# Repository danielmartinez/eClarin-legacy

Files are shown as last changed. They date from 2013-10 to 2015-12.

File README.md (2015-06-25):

eClarin
=======
eClarin is an Open Source project that brings you the opportunity to build an electronic aragonese bagpipe. It is based on the Arduino platform, 3D printing models and the USB MIDI Firmware.

How to build the hardware
-------------------------
The hardware can be built by following the steps in the "howto build the eChanter" http://www.echanter.com/home/howto-build. eClarin is also based on it, it is a cheap, easy and absolutly great way to make an electronic chanter... as they say: if you can solder, you can make it!

Maybe you will find helpfull the 3D models of chanters included here, you can print them with a 3D printer, and use them for the case.

How to load the firmware
------------------------
This project runs on an Arduino board, so you can get the sketch from this source code and load to it.

Once you load the sketch on the board you can program the Moco LUFA Firmware, that allows the PC to recognize the Arduino board as a standard USB MIDI controller. You can find that firmware and instructions here http://morecatlab.akiba.coocan.jp/lab/index.php/aruino/midi-firmware-for-arduino-uno-moco/?lang=en

I included that repository at this one as submodule, maybe you want to clone the whole project with --recursive option (or doing git submodule update if you already cloned whitout that option).

I want to play it!
------------------
Sure! When you have built it and have programmed the arduino board, plug it in your computer, it must be recognized as an USB MIDI controller that allows you to talk MIDI commands with your prefered MIDI synth software (Mine is fluidsynth).

Why eClarin?
------------
Yeah, that's a good question. All of this stuff is eChanter based and I can only thank the author for that. In a little tribute to him and using the word that names this part of the bagpipe (clarin means chanter), I chose eClarin for the project's name.

Can I help?
-----------
Maybe. If you think you can help, then you can help! Contact me about your suggestions, codes, ideas of whatever else you want, I'm pretty sure we can make it better together.

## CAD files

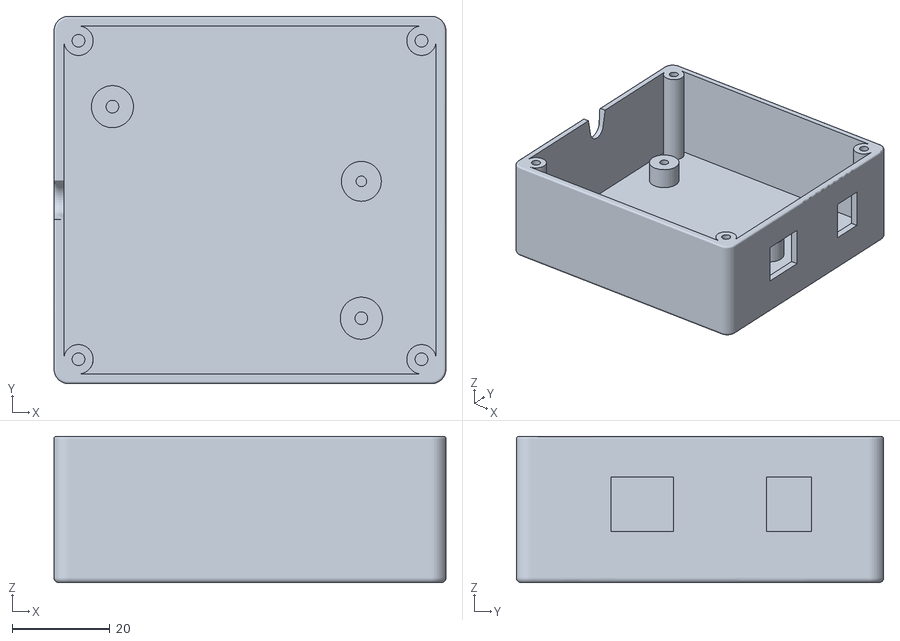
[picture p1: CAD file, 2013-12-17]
models/stl/cajita_base.stl
80.0 x 75.0 x 29.9

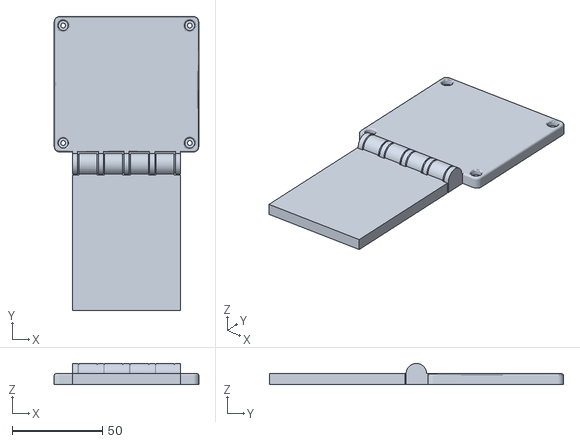
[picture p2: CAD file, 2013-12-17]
models/stl/cajita_tapa.stl
80.0 x 162.7 x 11.7

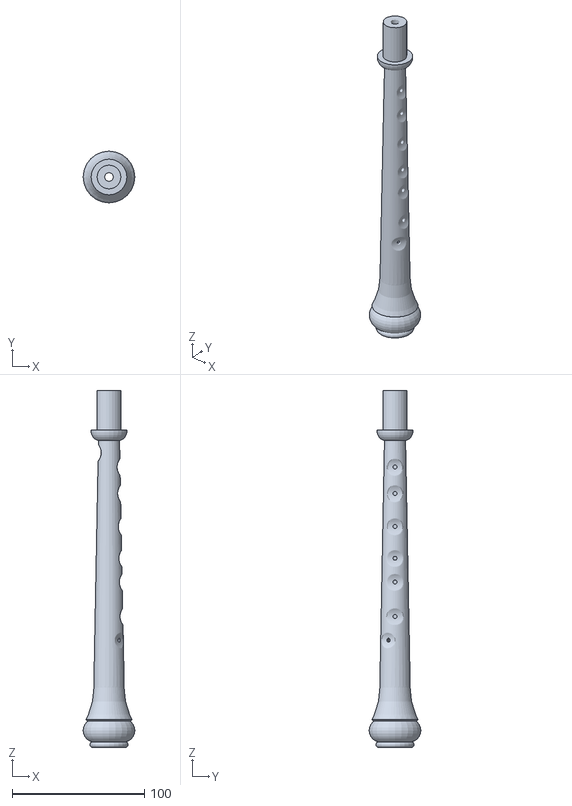
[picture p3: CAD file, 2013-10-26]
models/stl/clarin.stl
39.1 x 39.1 x 270.0

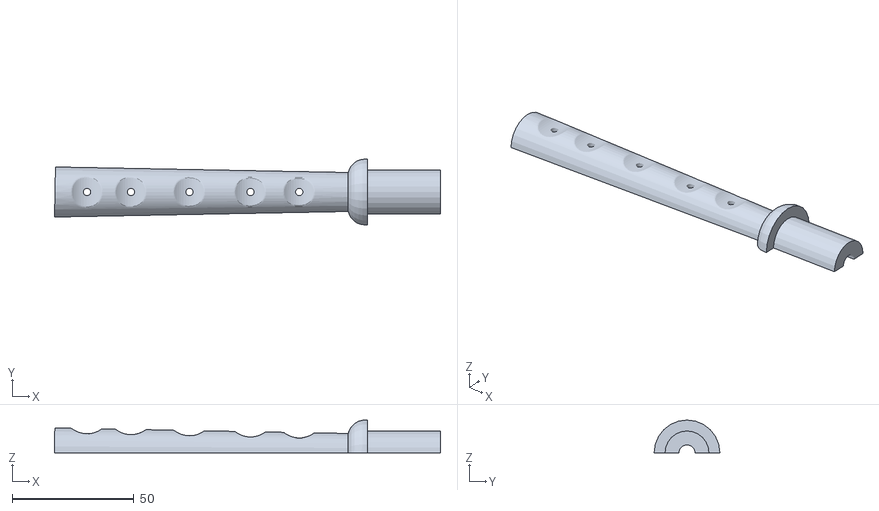
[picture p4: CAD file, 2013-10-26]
models/stl/clarincortado1.stl
158.2 x 27.0 x 13.5

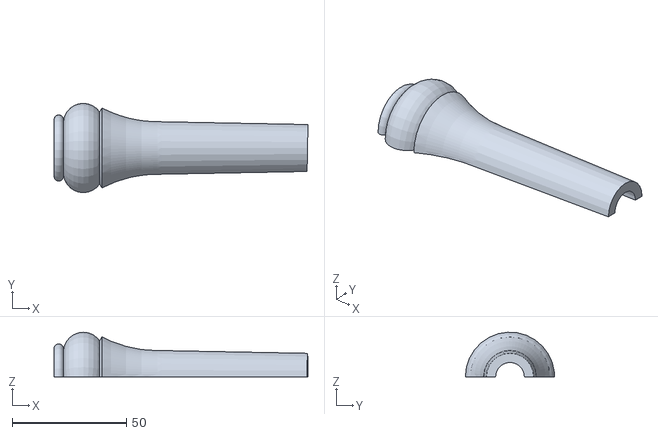
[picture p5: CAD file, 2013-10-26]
models/stl/clarincortado2.stl
111.2 x 39.1 x 19.5

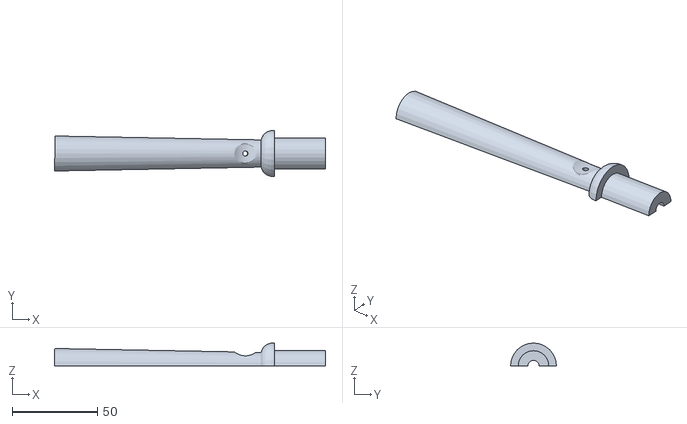
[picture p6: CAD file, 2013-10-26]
models/stl/clarincortado0.stl
159.1 x 27.0 x 13.5

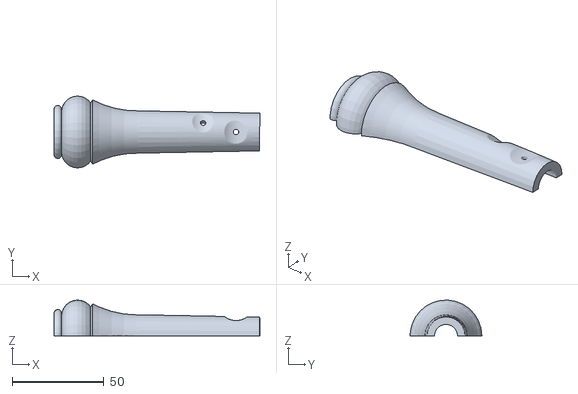
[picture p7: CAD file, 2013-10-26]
models/stl/clarincortado3.stl
112.2 x 39.1 x 19.5

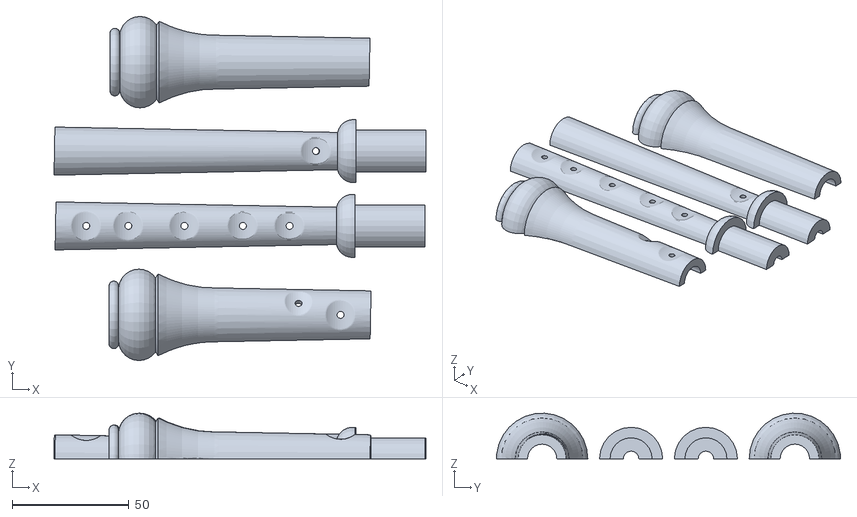
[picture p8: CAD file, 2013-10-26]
models/stl/clarinconjunto.stl
159.1 x 147.2 x 19.5

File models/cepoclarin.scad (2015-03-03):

radio=14;
altura=60;
grosor=2.5;
ancho=50;
largo=75;
diametroclarin=18;
alturaclarin=30;
$fn=200;
difference(){
  union(){
    //Cepo body
    difference() {
    translate([-(largo-2*radio)/2,-(ancho-2*radio)/2,0])
      minkowski() {
        cylinder(altura/2,r=radio);
        cube([largo-2*radio,ancho-2*radio,altura/2]);
      }
    translate([0,0,grosor/2])
      resize([(largo-grosor),(ancho-grosor),altura+grosor])
        translate([-(largo-2*radio)/2,-(ancho-2*radio)/2,0])
          minkowski() {
            cylinder(altura/2,r=radio);
            cube([largo-2*radio,ancho-2*radio,altura/2]);
          }
    }
    //Chanter support
    cylinder(d=diametroclarin+grosor+0.75,h=alturaclarin);
    //Slice switch support
    translate([grosor-0.7+(largo-radio)/2,-2.5,0]) cube([4,5,7+6+altura/2]);
    //VS1053 Module support
    translate([-2-45/2,-5.3-grosor+ancho/2,0]) cube([3,7,altura-5]);
    mirror([1,0,0]) translate([-2-45/2,-5.3-grosor+ancho/2,0]) cube([3,7,altura-5]);
    //ARDUINO NANO/MINI PRO support
    translate([7-largo/2,-8/2,0]) cube([6,8,15]);
  }
  //LED Hole
  translate([-2-largo/2,0,33]) rotate([0,90,0]) cylinder(d=3,h=2*grosor);
  //Slide switch Hole
  translate([(largo-radio)/2,-2,altura/2]) cube([grosor+5,4,7]);
  //Chanter Hole
  translate([0,0,-1]) cylinder(d=diametroclarin+0.75,h=alturaclarin+2);
  //VS1053
  translate([-45/2,-grosor-4+ancho/2,15]) cube([45,2,45]);
  //ARDUINO
  translate([9-largo/2,-20/2,10]) cube([1,20,15]);
}

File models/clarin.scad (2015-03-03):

$fn=200;
difference(){
rotate_extrude(){
difference() {
    union() {
      polygon([[0,0],[26/2,0],[26/2,16],[35/2,21],[23/2,21+26],[21/2,21+26+35],[20/2,21+26+35+30],[19/2,21+26+35+30+30],[18/2,21+26+35+30+30+30],[17/2,21+26+35+30+30+30+30],[16/2,21+26+35+30+30+30+30+30],[27/2,21+26+35+30+30+30+30+30+8],[18/2,21+26+35+30+30+30+30+30+8],[18/2,21+26+35+30+30+30+30+30+8+30],[0,21+26+35+30+30+30+30+30+8+30]]);
      translate([10,12,0]) circle(9);
      translate([13,2,0]) circle(2);
      intersection() {
        translate([4,1+21+26+35+30+30+30+30+30+8]) circle(10);
        translate([0,1+26+35+30+30+30+30+30+8])square([20,20]);
      }
    }
    translate([60+23/2,21+26] )circle(60);
  }
}

translate([-15,16,222]) rotate([0,90,0]) cylinder(h=30,r=10);
translate([-15,-16.1,212]) rotate([0,90,0]) cylinder(h=30,r=10);
translate([-15,-16.4,192]) rotate([0,90,0]) cylinder(h=30,r=10);
translate([-15,-16.9,167]) rotate([0,90,0]) cylinder(h=30,r=10);
translate([-15,-17.4,143]) rotate([0,90,0]) cylinder(h=30,r=10);
translate([-15,-17.8,125]) rotate([0,90,0]) cylinder(h=30,r=10);
translate([-15,-18.3,99]) rotate([0,90,0]) cylinder(h=30,r=10);
rotate([0,0,-30]) translate([-15,-18.9,81]) rotate([0,90,0]) cylinder(h=30,r=10);
}
//rotate([0,0,-90]) color("grey") translate([-98.5,-94.5,0]) import("clarin2.stl");

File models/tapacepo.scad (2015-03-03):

radio=14;
altura=1;
grosor=2.5;
ancho=50;
largo=75;
diametroclarin=18;
alturaclarin=30;
$fn=200;
difference () {
union() {
translate([-(largo-2*radio)/2,-(ancho-2*radio)/2,0])
      minkowski() {
        cylinder(altura/2,r=radio);
        cube([largo-2*radio,ancho-2*radio,altura/2]);
      }

translate([0,0,-1+grosor/2])
      resize([(largo-grosor),(ancho-grosor),altura+grosor+2])
        translate([-(largo-2*radio)/2,-(ancho-2*radio)/2,0])
          minkowski() {
            cylinder(altura/2,r=radio);
            cube([largo-2*radio,ancho-2*radio,altura/2]);
          }
}
translate([0,0,0.5+grosor/2])
      resize([(largo-grosor-grosor),(ancho-grosor-grosor),altura+grosor+5])
        translate([-(largo-2*radio)/2,-(ancho-2*radio)/2,0])
          minkowski() {
            cylinder(altura/2,r=radio);
            cube([largo-2*radio,ancho-2*radio,altura/2]);
          }
translate([12.5-45/2,-3-grosor-4+ancho/2,-1]) cylinder(d=5,h=10);
translate([largo/2-grosor-10,-4.5,-1]) cube([5,9,10]);
}

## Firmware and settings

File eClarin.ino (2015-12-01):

/*
 Copyright (C) 2015 Daniel Martinez <entaltoaragon@gmail.com>

 This program is free software; you can redistribute it and/or
 modify it under the terms of the GNU General Public License
 version 2 as published by the Free Software Foundation.
*/
/**************************************************************/
// CONFIGURATION
#define SENSOR_PINS             {2,3,4,5,6,7,8,9}
//#define BOTO_SENSOR           A4

#define VS1053_MIDI_SYNTH
#ifdef VS1053_MIDI_SYNTH
  #define XCS_PIN               A3
  #define XDCS_PIN              A2
  #define DREQ_PIN              A1
  #define XRST_PIN              A0
#else
  #define LED                   13 //can't use pin 13 for led if SPI communication is in use
#endif

#define SERIAL_MIDI              1

#define TRIGGER_VAL              8 // sensor trigger value (<val is on, >= val is off)
#ifdef BOTO_SENSOR
  #define BORDON_TRIGGER_VAL    20
  #define BORDONETA_TRIGGER_VAL 35
  #define CLARIN_TRIGGER_VAL    55
#endif

//#define SERIAL_DEBUG
#ifdef SERIAL_DEBUG
  //#define VERBOSE_DEBUG0   //Digitation events
  //#define VERBOSE_DEBUG1   //Start/stop events
#endif

//#define STORE_CONFIG_ON_EEPROM
#ifdef STORE_CONFIG_ON_EEPROM
  #define EEPROM_ADDR_INSTRUMENT 0
  #define EEPROM_ADDR_BORDON 1
  #define EEPROM_ADDR_BORDONETA 2
  #define EEPROM_ADDR_VOLUME 3
  #define CONFIG_RESET_START_POSITION B00000000
#endif

/**************************************************************/
// AUTOMATIC DEFINES
#include <Arduino.h>
#ifdef VS1053_MIDI_SYNTH
  #include <SPI.h>
  #include "V1053MidiSynth.h"
  V1053MidiSynth synth(XRST_PIN,DREQ_PIN,XDCS_PIN,XCS_PIN);
#endif
#ifdef SERIAL_MIDI
  #undef SERIAL_DEBUG
  #include <SoftwareSerial.h>
  SoftwareSerial midiSerial(0, SERIAL_MIDI);
#endif
#ifdef STORE_CONFIG_ON_EEPROM
  #include <EEPROM.h>
#endif
#ifdef SERIAL_DEBUG
  #include "GM1.h"
#endif

/**************************************************************/
//INITIALIZATION AND GLOBAL VARS
uint8_t pins[]=SENSOR_PINS;
byte currentpos=0, previouspos;
uint8_t previous=0x48;
uint8_t instrument=109, vol=127;
int fsrValue;
boolean bordon=true, bordoneta=true;
boolean bordonPlaying=false, bordonetaPlaying=false;
boolean playing=false;


/**************************************************************/
int msgMidi(int cmd, int note, int vel) {
#ifdef SERIAL_MIDI
  midiSerial.write(cmd);
  midiSerial.write(note);
  midiSerial.write(vel);
#endif
#ifdef VS1053_MIDI_SYNTH
  synth.midiWriteData(cmd,note,vel);
#endif
}

void setInstrument(uint8_t channel, uint8_t instrument) {
  msgMidi((0xC0 | channel),instrument,instrument);
}

void noteOn(uint8_t channel, uint8_t note) {
  msgMidi((0x90 | channel),note,120);
}

void noteOff(uint8_t channel, uint8_t note) {
  msgMidi((0x80 | channel),note,120);
}

void playNote(uint8_t want, uint8_t have) {
  if ((have!=want) && playing) {
    noteOff(0,have);
    noteOn(0,want);
    previous=want;
  }
}

uint8_t readCapacitivePin(int pinToMeasure) {
  // Variables used to translate from Arduino to AVR pin naming
  volatile uint8_t* port;
  volatile uint8_t* ddr;
  volatile uint8_t* pin;
  // Here we translate the input pin number from
  //  Arduino pin number to the AVR PORT, PIN, DDR,
  //  and which bit of those registers we care about.
  byte bitmask;
  port = portOutputRegister(digitalPinToPort(pinToMeasure));
  ddr = portModeRegister(digitalPinToPort(pinToMeasure));
  bitmask = digitalPinToBitMask(pinToMeasure);
  pin = portInputRegister(digitalPinToPort(pinToMeasure));
  // Discharge the pin first by setting it low and output
  *port &= ~(bitmask);
  *ddr  |= bitmask;
  delay(1);
  uint8_t SREG_old = SREG; //back up the AVR Status Register
  // Prevent the timer IRQ from disturbing our measurement
  noInterrupts();
  // Make the pin an input with the internal pull-up on
  *ddr &= ~(bitmask);
  *port |= bitmask;

  // Now see how long the pin to get pulled up. This manual unrolling of the loop
  // decreases the number of hardware cycles between each read of the pin,
  // thus increasing sensitivity.
  uint8_t cycles = 17;
       if (*pin & bitmask) { cycles =  0;}
  else if (*pin & bitmask) { cycles =  1;}
  else if (*pin & bitmask) { cycles =  2;}
  else if (*pin & bitmask) { cycles =  3;}
  else if (*pin & bitmask) { cycles =  4;}
  else if (*pin & bitmask) { cycles =  5;}
  else if (*pin & bitmask) { cycles =  6;}
  else if (*pin & bitmask) { cycles =  7;}
  else if (*pin & bitmask) { cycles =  8;}
  else if (*pin & bitmask) { cycles =  9;}
  else if (*pin & bitmask) { cycles = 10;}
  else if (*pin & bitmask) { cycles = 11;}
  else if (*pin & bitmask) { cycles = 12;}
  else if (*pin & bitmask) { cycles = 13;}
  else if (*pin & bitmask) { cycles = 14;}
  else if (*pin & bitmask) { cycles = 15;}
  else if (*pin & bitmask) { cycles = 16;}

  // End of timing-critical section; turn interrupts back on if they were on before, or leave them off if they were off before
  SREG = SREG_old;

  // Discharge the pin again by setting it low and output
  //  It's important to leave the pins low if you want to 
  //  be able to touch more than 1 sensor at a time - if
  //  the sensor is left pulled high, when you touch
  //  two sensors, your body will transfer the charge between
  //  sensors.
  *port &= ~(bitmask);
  *ddr  |= bitmask;

  return cycles;
}

uint8_t readPins(){
  uint8_t positions=0, val;
  for (uint8_t i = 0; i < 8; i++) {
    val=readCapacitivePin(pins[i]);
    if (val <= TRIGGER_VAL) bitClear(positions,i);
    else bitSet(positions,i);
    #ifdef VERBOSE_DEBUG0
      Serial.print(val);
      Serial.print(' ');
    #endif
  }
  #ifdef VERBOSE_DEBUG0
    Serial.print(positions,BIN);
    Serial.println(" ");
  #endif
  return positions;
}

void readConfig(){
  #ifdef STORE_CONFIG_ON_EEPROM
    instrument=EEPROM.read(EEPROM_ADDR_INSTRUMENT);
    bordon=EEPROM.read(EEPROM_ADDR_BORDON);
    bordoneta=EEPROM.read(EEPROM_ADDR_BORDONETA);
    vol=EEPROM.read(EEPROM_ADDR_VOLUME);
  #endif
  #ifdef SERIAL_DEBUG
    Serial.println("Settings loaded from EEPROM");
  #endif
}

void writeConfig(){
  #ifdef STORE_CONFIG_ON_EEPROM
    EEPROM.write(EEPROM_ADDR_INSTRUMENT,instrument);
    EEPROM.write(EEPROM_ADDR_BORDON,bordon);
    EEPROM.write(EEPROM_ADDR_BORDONETA,bordoneta);
    EEPROM.write(EEPROM_ADDR_VOLUME,vol);
    #ifdef SERIAL_DEBUG
      Serial.print("Settings saved to EEPROM - Instrument: ");
      Serial.print(instrument);
      Serial.print(", bordon ");
      if (bordon) Serial.print("ON");
      else Serial.print("OFF");
      Serial.print(", bordoneta ");
      if (bordoneta) Serial.print("ON");
      else Serial.print("OFF");
      Serial.print(", volume: ");
      Serial.print(vol);
      Serial.println("");
    #endif
  #endif
}

void startClarin() {
  noteOff(0,previous);
  setInstrument(0,instrument);
  playing=true;
  playNote(previous,0);
  #ifndef VS1053_MIDI_SYNTH
    digitalWrite(LED,HIGH);
  #endif
  #ifdef VERBOSE_DEBUG1
    Serial.println("Clarin start");
  #endif
}

void stopClarin() {
  noteOff(0,previous);
  playing=false;
  #ifndef VS1053_MIDI_SYNTH
    digitalWrite(LED,LOW);
  #endif
  #ifdef VERBOSE_DEBUG1
    Serial.println("Clarin stop");
  #endif
}

void startBordon() {
  noteOff(1,0x30);
  setInstrument(1,instrument);
  if (bordon) noteOn(1,0x30);
  bordonPlaying=true;
  #ifdef VERBOSE_DEBUG1
    Serial.println("Bordon start");
  #endif
}

void stopBordon() {
  noteOff(1,0x30);
  bordonPlaying=false;
  #ifdef VERBOSE_DEBUG1
    Serial.println("Bordon stop");
  #endif
}

void startBordoneta() {
  noteOff(2,0x3C);
  setInstrument(2,instrument);
  if (bordoneta) noteOn(2,0x3C);
  bordonetaPlaying=true;
  #ifdef VERBOSE_DEBUG1
    Serial.println("Bordoneta start");
  #endif
}

void stopBordoneta() {
  noteOff(2,0x3C);
  bordonetaPlaying=false;
  #ifdef VERBOSE_DEBUG1
    Serial.println("Bordoneta stop");
  #endif
}

void startPlayback() {
  startBordon();
  startBordoneta();
  startClarin();
  #ifdef VERBOSE_DEBUG1
    Serial.println("Playback start");
  #endif
}

void stopPlayback() {
  stopClarin();
  stopBordoneta();
  stopBordon();
  #ifdef VERBOSE_DEBUG1
    Serial.println("Playback stop");
  #endif
}

void setInstrument() {
  stopPlayback();
  setInstrument(0,instrument);
  setInstrument(1,instrument);
  setInstrument(2,instrument);
  #ifdef SERIAL_DEBUG
    char buffer[30];
    Serial.print("Instrument set to ");
    strcpy_P(buffer,(char*)pgm_read_word(&(instrumentNames[instrument])));
    Serial.println(buffer);
  #endif
  startPlayback();
}

void setup() {
  #ifdef VS1053_MIDI_SYNTH
    synth.begin();
  #else
    pinMode(LED,OUTPUT);
  #endif
  #ifdef SERIAL_MIDI
    midiSerial.begin(31250);
  #elif defined(SERIAL_DEBUG)
    Serial.begin(115200);
  #endif
  #ifdef fsrAnalogPin
    pinMode(fsrAnalogPin, INPUT);
  #endif
  delay(5);
  #ifdef STORE_CONFIG_ON_EEPROM
    if (readPins()==CONFIG_RESET_START_POSITION) {
      writeConfig();
      #ifdef SERIAL_DEBUG
        Serial.print("DEFAULT ");
      #endif
    }
    else {
      readConfig();
      #ifdef SERIAL_DEBUG
        Serial.print("Saved ");
      #endif
    }
  #endif
  #ifdef SERIAL_DEBUG
    Serial.print("Settings loaded - Instrument: ");
    Serial.print(instrument);
    Serial.print(", bordon ");
    if (bordon) Serial.print("ON");
    else Serial.print("OFF");
    Serial.print(", bordoneta ");
    if (bordoneta) Serial.print("ON");
    else Serial.print("OFF");
    Serial.print(", volume: ");
    Serial.print(vol);
    Serial.println("");
  #endif
  setInstrument();
}

void loop() {
    #ifdef BOTO_SENSOR
      fsrValue=analogRead(BOTO_SENSOR);
      if (fsrValue<BORDON_TRIGGER_VAL) {
        if (bordonPlaying) stopBordon();
      }
      else if (!bordonPlaying) startBordon();
      if (fsrValue<BORDONETA_TRIGGER_VAL) {
        if (bordonetaPlaying) stopBordoneta();
      }
      else if (!bordonetaPlaying) startBordoneta();
      if (fsrValue<CLARIN_TRIGGER_VAL)  {
        if (playing) stopClarin();
      }
      else if (!playing) startClarin();
    #endif
    currentpos=readPins();
    if (currentpos!=previouspos)
    switch (currentpos) {
     case B01111101: ;; //DoA
     case B00000000: playNote(0x54,previous); break; //DoA
     case B00000001: ;; //Si
     case B01110001: playNote(0x53,previous); break; //Si
     case B00000101: ;; //Sib
     case B00000010: ;; //Sib
     case B01110101: playNote(0x52,previous); break; //Sib
     case B00000011: ;; //La
     case B01110011: playNote(0x51,previous); break; //La
     case B00001011: ;; //Lab
     case B00101011: ;; //Lab
     case B01101011: ;; //Lab
     case B01110110: playNote(0x50,previous); break; //Lab
     case B00000111: ;; //Sol
     case B01110111: playNote(0x4F,previous); break; //Sol
     case B00110111: playNote(0x4E,previous); break; //Fa#
     case B00001111: ;; //Fa
     case B11101111: ;; //Fa
     case B01101111: playNote(0x4D,previous); break; //Fa
     case B00011111: playNote(0x4C,previous); break; //Mi
     case B01011111: playNote(0x4B,previous); break; //Mib
     case B00111111: playNote(0x4A,previous); break; //Re
     case B10111111: playNote(0x49,previous); break; //Do#
     case B01111111: playNote(0x48,previous); break; //Do
     case B11111111: playNote(0x47,previous); break; //SiB
     
     case B10000010: ++instrument%=128; setInstrument(); writeConfig(); break;
     case B10000100: --instrument%=128; setInstrument(); writeConfig(); break;
     case B10001000: if (bordon=!bordon) startBordon();
                     else stopBordon();
                     #ifdef SERIAL_DEBUG
                       Serial.print("Set bordon ");
                       if (bordon) Serial.println("ON");
                       else Serial.println("OFF");
                     #endif
                     writeConfig(); break;
     case B10010000: if (bordoneta=!bordoneta) startBordoneta();
                     else stopBordoneta();
                     #ifdef SERIAL_DEBUG
                       Serial.print("Set bordoneta ");
                       if (bordoneta) Serial.println("ON");
                       else Serial.println("OFF");
                     #endif
                     writeConfig(); break;
     case B10100000: if (playing=!playing) startClarin();
                     else stopClarin(); break;
     /*case B10000011: msgMidi(0xB0,0x07,vol+=5); break;
     case B10000101: msgMidi(0xB0,0x07,vol-=5); break;*/
    }
    previouspos=currentpos;
}

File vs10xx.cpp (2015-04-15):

/*
 * vs10xx.cpp
 * A library for MusicShield 2.0
 *
 * Copyright (c) 2012 seeed technology inc.
 * Website    : www.seeed.cc
 * Author     : Jack Shao (jacky.shaoxg@gmail.com)
 * Create Time: Mar 2014
 * Change Log :
 *
 * The MIT License (MIT)
 *
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
 * THE SOFTWARE IS PROVIDED "AS IS", WITHOUT WARRANTY OF ANY KIND, EXPRESS OR
 * IMPLIED, INCLUDING BUT NOT LIMITED TO THE WARRANTIES OF MERCHANTABILITY,
 * FITNESS FOR A PARTICULAR PURPOSE AND NONINFRINGEMENT. IN NO EVENT SHALL THE
 * AUTHORS OR COPYRIGHT HOLDERS BE LIABLE FOR ANY CLAIM, DAMAGES OR OTHER
 * LIABILITY, WHETHER IN AN ACTION OF CONTRACT, TORT OR OTHERWISE, ARISING FROM,
 * OUT OF OR IN CONNECTION WITH THE SOFTWARE OR THE USE OR OTHER DEALINGS IN
 * THE SOFTWARE.
 */


#include <SPI.h>
#include "vs10xx.h"

//software patch for MIDI Play
const unsigned short gVS1053_MIDI_Patch[28]={
/*if you don't let GPIO1 = H,please send this patch by spi*/
0x0007, 0x0001, 0x8050, 0x0006, 0x0014, 0x0030, 0x0715, 0xb080, /* 0 */
0x3400, 0x0007, 0x9255, 0x3d00, 0x0024, 0x0030, 0x0295, 0x6890, /* 8 */
0x3400, 0x0030, 0x0495, 0x3d00, 0x0024, 0x2908, 0x4d40, 0x0030, /* 10 */
0x0200, 0x000a, 0x0001, 0x0050,
};

VS10XX::VS10XX(uint8_t _VS_XRESET, uint8_t _VS_DREQ, uint8_t _VS_XDCS, uint8_t _VS_XCS):
  VS_XRESET(_VS_XRESET), VS_DREQ(_VS_DREQ), VS_XDCS(_VS_XDCS), VS_XCS(_VS_XCS)
{
}

/*
 **@ function name: init
 **@ usage:init the vs10xx chip
 **@ input:none
 **@ retval:none
*/
void VS10XX::init(void)
{
  SPI.begin();
  SPI.setClockDivider(SPI_CLOCK_DIV16);
  initIO();
  reset();
}

/*
 **@ function name: initForMidiFmt
 **@ usage:init the vs10xx chip for midi Mode
 **@ input:none
 **@ retval:none
*/
void VS10XX::initForMidiFmt(void)
{
  //init IO
  initIO();

  //init SPI
  SPI.begin();
  SPI.setBitOrder(MSBFIRST);
  SPI.setDataMode(SPI_MODE0);
  SPI.setClockDivider(SPI_CLOCK_DIV16);
  //SPI.transfer(0xFF);	//transfer a dump

  //reset the chip
  reset();
  //load MIDI plugin
  loadMidiPlugin();
}

void VS10XX::initIO(void)
{
  pinMode(VS_XRESET, OUTPUT);
  pinMode(VS_DREQ, INPUT);
  pinMode(VS_XDCS, OUTPUT);
  pinMode(VS_XCS, OUTPUT);
  digitalWrite(VS_XDCS, HIGH);
  digitalWrite(VS_XCS, HIGH);
}

void VS10XX::writeRegister(unsigned char addressbyte, unsigned char highbyte, unsigned char lowbyte)
{
  // while (!readDREQ());
  deselectDataBus();
  selectControlBus();
  SPI.transfer(VS_WRITE_COMMAND);
  SPI.transfer((addressbyte));
  SPI.transfer((highbyte));
  SPI.transfer((lowbyte));
  deselectControlBus();
}

void VS10XX::writeRegister(unsigned char addressbyte, unsigned int value)
{
  writeRegister(addressbyte, value >>8, value & 0xff);
}

void VS10XX::writeData(unsigned char *databuf, unsigned char datalen)
{
  selectDataBus();
  while (!readDREQ());
  while (datalen--)
  {
    SPI.transfer(*databuf++);
  }
  deselectDataBus();
}

unsigned int VS10XX::readRegister(unsigned char addressbyte)
{
  unsigned int result = 0;
  unsigned char highbyte = 0;
  unsigned char lowbyte = 0;
  deselectDataBus();
  selectControlBus(); //XCS = 0
  SPI.transfer(VS_READ_COMMAND); //send read command
  SPI.transfer(addressbyte);    //send register address
                                //be careful: when read 0xff,dump it,and read agin
                                //while((h = SPIGetChar())== 0xff);
  highbyte = SPI.transfer(0xff);
  //while((l = VsReadByte())== 0xff);
  lowbyte = SPI.transfer(0xff);

  result = (((unsigned int)highbyte << 8) | lowbyte);
  deselectControlBus();
  return result;
}
// reset for vs10xx
void VS10XX::reset(void)
{
  putInReset();
  delay(100); //it is a must
  /* Send dummy SPI byte to initialize atmel SPI */
  ////SPIPutCharWithoutWaiting(0xFF);
  deselectControlBus();
  deselectDataBus();
  releaseFromReset();
  while (!readDREQ());
  /* Set clock register, doubler etc. */
  writeRegister(SPI_CLOCKF, 0xc0, 0x00);
  Serial.print("\r\nVS10xx Clock Frq: 0x");
  Serial.println(readRegister(SPI_CLOCKF), HEX);
  /* Wait for DREQ */
  while (!readDREQ());
  softReset(); //comment this, as it will be executed everytime playing a music file.

  writeRegister(SPI_WRAMADDR, 0xc0, 0x13);

  /* Switch on the analog parts */
  setVolume(40, 40);
  //setVolume(0xff,0xff);
  //SPISetFastClock();
}
/** Soft Reset of VS10xx (Between songs) */
void VS10XX::softReset(void)
{
  /* Soft Reset of VS10xx */
  writeRegister(SPI_MODE, 0x08, 0x04); /* Newmode, Reset, No L1-2 */
  //Delay(1);
  while (!readDREQ()); /* wait for startup */
  //setup I2S (see page77 of the datasheet of vs1053 )
  //set GPIO0 as output
  writeRegister(SPI_WRAMADDR, 0xc0, 0x17);
  writeRegister(SPI_WRAM, 0x00, 0xf0);
  //enable I2S (MCLK enabled, 48kHz sample rate)
  writeRegister(SPI_WRAMADDR, 0xc0, 0x40);
  writeRegister(SPI_WRAM, 0x00, 0x0C);
  while (!readDREQ());
  //LoadUserPatch();
}
/** Set VS10xx Volume Register */
void VS10XX::setVolume(unsigned char leftchannel, unsigned char rightchannel)
{
  writeRegister(11, (leftchannel), (rightchannel));
}

void VS10XX::sendZerosToVS10xx(void)
{
  unsigned int i;
  selectDataBus();
  for (i = 0; i < 2048; i++)
  {
    while (!readDREQ());
    SPI.transfer(0);
  }
  deselectDataBus();
}

/*
 **@ function name: loadMidiPatch
 **@ usage:load a software patch for vs10xx
 **@ input:none
 **@ retval:none
*/
void VS10XX::loadMidiPlugin(void)
{
  int i=0;
  Serial.print("load MIDI Plugin...\r\n");
  while(i < sizeof(gVS1053_MIDI_Patch)/sizeof(gVS1053_MIDI_Patch[0]))
  {
    unsigned short addr, n, val;
    addr = gVS1053_MIDI_Patch[i++];
    n = gVS1053_MIDI_Patch[i++];
    while(n--)
    {
      val = gVS1053_MIDI_Patch[i++];
      writeRegister(addr, val >> 8, val&0xff);
    }
  }
  Serial.print("done\r\n");
}
/****************The end***********************************************/

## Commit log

2013-10-26 Added main arduino sketch file
2013-10-26 Added a chanter model stl files
    [clarin2.stl, clarinconjunto.stl, clarincortado0.stl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]
2013-12-17 Arduino case model with FRS lid mount
    [cajita_base.stl, cajita_tapa.stl]
2015-02-16 Updated readCapacitivePin code from http://playground.arduino.cc/Code/CapacitiveSensor
2015-03-03 OpenSCAD files for portable model
    [cepoclarin.scad, clarin.scad, tapacepo.scad]
2015-03-06 Old models moved to models/stl directory
    [cajita_base.stl, cajita_tapa.stl, clarin.stl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]
2015-12-01 Replace BORDON by BOTO an sensor name, change default sensor pin to A4, reorder some code
    [eClarin.ino]
